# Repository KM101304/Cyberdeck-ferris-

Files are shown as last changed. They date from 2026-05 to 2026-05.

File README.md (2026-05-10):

# Ferris FieldDeck 11

A backpack-portable asymmetrical clamshell cyberdeck built around an 11-inch USB-C tablet and a Ferris Sweep-inspired low-profile split keyboard.

This repo contains a parametric OpenSCAD prototype package intended for real 3D printing and mechanical iteration.

## Locked Design

| Feature | Value |
|---|---:|
| Closed footprint | 282 x 176 mm |
| Lower shell height | 24.8 mm rear structural height |
| Upper lid thickness | 11.2 mm |
| Opening angle target | 122 degrees nominal, 120-125 degree working range |
| Tablet envelope | Samsung Galaxy Tab A9+, 257.1 x 168.7 x 6.9 mm |
| Keyboard | Sweep v2.2 Choc low-profile 34 key |
| Shell material | PETG |
| Structural inserts | M2.5 and M3 brass heat-set inserts |
| Hinge style | Dual compact friction hinges |

## Files

```text
scad/fielddeck.scad          Main parametric source
scad/parts/*.scad            One wrapper per printable part
scripts/export_stls.sh       Batch STL export script
scripts/export_web_models.sh Batch website model export script
exports/stl/                 STL output directory
docs/PRINTING.md             Bambu/PETG print settings
docs/BOM.md                  Hardware, fasteners, and electronics
docs/ASSEMBLY.md             Build sequence and validation checks
docs/AUDIT.md                Engineering audit and remaining prototype checks
docs/PARTS_LOCK.md           Real selected parts and mechanical envelopes
docs/WIRING.md               Keyboard, power, and USB wiring plan
hardware/keyboard/Sweep/     Vendored Sweep v2.2 PCB source and gerbers
hardware/keyboard/fielddeck_sweep_compat/ FieldDeck-specific keyboard PCB placement and wiring files
```

## Printable Parts

| Part | Purpose |
|---|---|
| `lower_left` | Left lower shell with left keyboard tray |
| `lower_right` | Right lower shell with right keyboard tray |
| `lower_center_spine` | Mechanical joiner, hinge spine reinforcement, central seam cover |
| `bottom_cover` | Removable service panel |
| `upper_lid_frame` | Tablet retention frame |
| `upper_lid_back` | Ribbed lid back panel |
| `lower_hinge_block_left/right` | Lower hinge mounts |
| `upper_hinge_block_left/right` | Upper hinge mounts |
| `tablet_bracket` | Hooked sliding tablet retention bracket, print 4 |
| `keyboard_plate_left/right` | Choc switch plates |
| `cable_cover_short/long` | Internal cable channel covers |
| `battery_strap` | Retains internal USB-C PD pack/module |
| `fit_coupon` | Insert, screw, slot, and bracket clearance test |

## Simulated Components

The assembly preview and web viewer include simulated internal components:

- 11-inch tablet massing
- split keyboard PCBs
- Kailh Choc switch bodies
- keycaps
- controller board
- USB-C port boards
- protected battery module
- hinge hardware
- keyboard, battery, and hinge-loop cable runs

The GitHub Pages viewer has an `Internals` mode that makes the shell transparent so those simulated components can be inspected.

## Real Parts Locked

This revision is built around a Samsung Galaxy Tab A9+ Wi-Fi tablet, Sweep v2.2 Choc PCB geometry, and Pro Micro-footprint USB-C RP2040 controllers. See [docs/PARTS_LOCK.md](docs/PARTS_LOCK.md) for selected parts, dimensions, and source links.

## Export STLs

Install OpenSCAD, then run:

```bash
scripts/export_stls.sh
```

The generated files will be placed in:

```text
exports/stl/
```

You can also open any file in `scad/parts/` directly in OpenSCAD and export that individual part.

## Preview The Design

Rendered previews are generated from the same OpenSCAD assembly source as the printable parts.

The GitHub Pages site lives in `docs/` and includes an interactive Three.js STL viewer:

```text
https://km101304.github.io/Cyberdeck-ferris-/
```

```bash
scripts/render_previews.sh
```

Open these files:

| View | File |
|---|---|
| Keyboard/open isometric | [exports/preview/fielddeck_keyboard_iso.png](exports/preview/fielddeck_keyboard_iso.png) |
| Keyboard/top layout | [exports/preview/fielddeck_keyboard_top.png](exports/preview/fielddeck_keyboard_top.png) |
| Display/rear isometric | [exports/preview/fielddeck_open_iso.png](exports/preview/fielddeck_open_iso.png) |
| Display/rear front | [exports/preview/fielddeck_open_front.png](exports/preview/fielddeck_open_front.png) |
| Side profile | [exports/preview/fielddeck_open_side.png](exports/preview/fielddeck_open_side.png) |
| Closed clearance | [exports/preview/fielddeck_closed_iso.png](exports/preview/fielddeck_closed_iso.png) |

## Print First

Before committing to the large shell pieces, print these validation parts:

1. `tablet_bracket`
2. `lower_hinge_block_left`
3. `keyboard_plate_left`
4. `cable_cover_short`
5. `fit_coupon`

Confirm insert fit, hinge hardware spacing, Choc switch fit, and cable clearance.

## Manufacturing Notes

- Use PETG for the main structure.
- Use PETG-CF or nylon for hinge blocks when possible.
- Use 4 wall loops and 25% gyroid infill for shell parts.
- Use 40% infill and 5 wall loops for hinge blocks.
- Add 0.8-1.0 mm TPU, EVA, felt, or Poron pads wherever the tablet contacts printed plastic.
- Tune the tablet bracket slots so the hooks overlap the glass/edge by 2.0-2.5 mm after pads are installed.
- Do not install a raw lithium pack without a protected BMS, fuse, and proper charging board. The intended prototype uses an enclosed slim USB-C PD power bank/module.

## CAD Iteration

The OpenSCAD package is the printable mechanical baseline. For Fusion 360 refinement:

1. Export the part STLs from OpenSCAD.
2. Import into Fusion as reference meshes.
3. Rebuild critical surfaces parametrically if you need production-level CAD.
4. Preserve the dimensions and interface locations from `scad/fielddeck.scad`.

## Current Status

The repo now contains both the parametric OpenSCAD source and generated STL files in `exports/stl/`. The STL export was verified with OpenSCAD CGAL rendering; every exported part reported as a valid simple 3D object. See [docs/AUDIT.md](docs/AUDIT.md) for the latest engineering audit.

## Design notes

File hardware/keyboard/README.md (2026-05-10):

# Keyboard PCB Package

This project uses the open-source Sweep v2.2 low-profile Choc PCB as the production keyboard PCB.

The upstream hardware source is vendored here:

```text
hardware/keyboard/Sweep/
```

Key files:

```text
hardware/keyboard/Sweep/Sweep v2.2/sweepv2.kicad_pcb
hardware/keyboard/Sweep/Sweep v2.2/sweepv2_plate.kicad_pcb
hardware/keyboard/Sweep/Sweep v2.2/sweepv2.2_gerber.zip
```

The Gerber ZIP is ready to upload to a PCB manufacturer. The cyberdeck shell uses its own recessed trays and mounting bosses, so the original Sweep case/plate geometry should be treated as a PCB reference rather than the final enclosure.

FieldDeck-specific wiring, placement, and mechanical integration files are in:

```text
hardware/keyboard/fielddeck_sweep_compat/
```

Use Pro Micro-footprint USB-C RP2040 controllers for the FieldDeck build. The earlier XIAO controller concept is no longer recommended because it is a poor fit for the direct-pin Sweep v2.2 architecture.

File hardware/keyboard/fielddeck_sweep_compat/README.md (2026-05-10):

# FieldDeck Sweep-Compatible Keyboard PCB Package

This folder defines the cyberdeck-specific keyboard integration.

Decision: use the open-source Sweep v2.2 Choc PCB geometry as the manufacturable base, because it is generic, easy to find online, already proven by the keyboard community, and already vendored in this repo with a Gerber ZIP.

The FieldDeck-specific changes are enclosure and wiring decisions:

- Pro Micro-footprint USB-C RP2040 controllers instead of XIAO controllers.
- Internal keyed JST-SH split interconnect instead of exposed TRRS.
- Recessed tray and printed switch plate matched to the cyberdeck shell.
- Lowered keyboard mounting plane for clamshell closure clearance.

## Fab-Ready PCB Source

Use the upstream Sweep v2.2 Gerber ZIP:

```text
../Sweep/Sweep v2.2/sweepv2.2_gerber.zip
```

The archive contains a JLCPCB-ready package named `sweepv2.1_216.92x86.863892mm_for_JLCPCB/`.

## FieldDeck Design Files

| File | Purpose |
|---|---|
| `switch_coordinates.csv` | Switch center coordinates used by the CAD and PCB spec |
| `direct_pin_netlist.csv` | One-GPIO-per-key wiring map for each half |
| `interconnect_pinout.csv` | Internal keyed split interconnect pinout |
| `pcb_mechanical_spec.md` | Mechanical envelope, mounting holes, and clearance rules |
| `fielddeck_keyboard_layout.svg` | Human-readable board/layout drawing |

## Controller

Use SparkFun Pro Micro RP2040 or another Pro Micro-footprint USB-C RP2040 controller with equivalent pin availability. SparkFun lists the board as USB-C, Pro Micro footprint, and `1.3 in x 0.7 in`, which is inside the CAD controller envelope.

## Why Not XIAO

The Seeed XIAO RP2040 is attractive and small, but this design uses a direct-pin Sweep-style circuit. Each 17-key half needs 17 switch GPIO plus split communication and reset/programming support. XIAO pushes that into an avoidable I/O compromise. Pro Micro RP2040 keeps the board generic and sourceable.

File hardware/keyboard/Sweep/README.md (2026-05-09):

# Sweep
<!--
           ___                        ___
      ___ |   | ___ ___      ___ ___ |   | ___
 ___ |   |`___`|   |   |    |   |   |`___`|   | ___
|   |`___`|   |`___`___`    `___`___`|   |`___`|   |
`___`|   |`___`|   |   |    |   |   |`___`|   |`___`
|   |`___`|   |`___`___`    `___`___`|   |`___`|   |
`___`|   |`___`|   |   |    |   |   |`___`|   |`___`
|   |`___`     `___`___`    `___`___`     `___`|   |
`___`           ___ ___      ___ ___           `___`
               |   |   |    |   |   |
               `___`___`    `___`___`
-->
>  sweep-hero  
> <sub>Bluetooth Sweep 2 + MBK Legend Keycaps</sub>

<span>
  <a href="https://discord.gg/czXcTXbsgU">
    
  </a>
  
  
  
</span>

## What is sweep?

Sweep is a version of the more fabulous [Ferris](https://github.com/pierrechevalier83/ferris) by [Pierre Chevalier](https://github.com/pierrechevalier83/) that uses a daughter board like a promicro, elite-c, bit-c, nice!nano etc. instead of using onboard components.

## What are the different types?

⭐ Sweep 2 - Recommended Choc v1 board with all the features.  
⭕ Sweep Half Swept - Same as Sweep 2, but with a reversible pro-micro footprint.  
⭕ Sweep Bling MX - An MX only Sweep that features Kailh's hotswap sockets and a stacked case.  
⭕ Sweep Bling LP - A Choc v1 only Sweep that features Kailh's hotswap sockets.  
⭕ Sweep High - Same as the Sweep 2, but trades choc spacing for compatibility with more switches and keycaps.  
⭕ Sweep High M - A soldered MX only Sweep, with a reversible PCB design.  
⭕ Sweep Mini - The only version that supports Choc minis.  

| Device | On/Off Switch<sup>[1]</sup> | Reversible PCB<sup>[2]</sup> | Choc V1 | Choc V2 | Choc Mini | MX & Alps | Choc Spacing<sup>[3]</sup> | Tenting<sup>[4]</sup> | Hot Swap |
| :--- | :---: | :---: | :---: | :---: | :---: | :---: | :---: | :---: | :---: |
| Sweep2.x | ✔ | | ✔ | | | | ✔ | ✔ | Mill-Max (optional) |
| Sweep Bling LP | ✔ | | ✔ | | | | ✔ | ✔ | Kailh (required) |
| Sweep Bling MX | ✔ | ✔ | | | | ⚠<br/><sup>[5]</sup> | | ✔ | Kailh (required) |
| Sweep High | ✔ | | ✔ | ✔ | | ✔ | | ✔ |
| Sweep High M | ✔ | ✔ | | | | MX | | ✔ | |
| Sweep Half Swept  | ✔ | ✔ | ✔ | | | | ✔ | ✔ | Mill-Max (optional) |
| Sweep Mini | | ✔ | | | ✔ | | ✔ | |

> Note: All versions support bluetooth with Nice!Nano

*<sup>[1]</sup> An on/off switch is recommended for bluetooth builds.*  
*<sup>[2]</sup> With a reversible PCB it's easier to make mistakes during assembly, but it allows you to purchase less boards.*  
*<sup>[3]</sup> Choc spaced boards have the switches in a tighter grid. This provides a better final look but is only compatible with some choc keycaps. (e.g. MBK)*  
*<sup>[4]</sup> Supports splitkb's [tenting puck.](https://splitkb.com/products/tenting-puck?_pos=1&_psq=tenting%20&_ss=e&_v=1.0)*  
*<sup>[5]</sup> MX + kailh hotswap ONLY. Alps are NOT supported.*  

## Components list

To build and use a Sweep you will need:

* 1x PCB Kit
* 2x promicro compatible boards or 2 nice!nanos.
* 34 switches of a compatible type (refer to the compatibility table)
* 34 keycaps
* 2x reset switches (optional; [B3U-1000P(M)](https://github.com/davidphilipbarr/Sweep/issues/20))
* Some little rubber feet/bumpers
* 2x power switches (optional if supported; MSK 12C02)
* 1x TRRS (not TRS!) cable (wired build only)
* 2x TRRS Jack [PJ-320A] (wired build only)
* 1 USB Cable (depends on your micro-controller choice)

## How do I make this thing?

<a href="https://www.youtube.com/watch?v=fBPu7AyDtkM" target="_blank">
  
</a>

## Firmware

The firmware can be found [with the Ferris  firmware as part of QMK](https://github.com/qmk/qmk_firmware/tree/master/keyboards/ferris/sweep).

Firmware for zmk and bluemicro_ble is called ["Cradio"](https://zmk.dev/docs/hardware/).

## Who made this?

* [Pierre Chevalier](https://github.com/pierrechevalier83)
* [David Barr](https://github.com/davidphilipbarr)
* [Ibnu Daru Aji](https://github.com/ibnuda/)
* [Duccio](https://github.com/duckyb)

## Featured Forks ✨

* [Sweep Gateron](https://github.com/drewlwhitney/Sweep-Gateron) by drewlwhitney: *A Sweep High modded with Gateron-LP KS-33 support.*

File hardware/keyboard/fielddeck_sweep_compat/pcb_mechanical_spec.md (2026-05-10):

# FieldDeck Sweep-Compatible PCB Mechanical Spec

## Board Envelope

| Item | Value |
|---|---:|
| Per-half PCB target envelope | 108 x 86 x 1.6 mm |
| Printed tray pocket | 116 x 90 mm |
| Printed switch plate | 112 x 88 x 1.6 mm |
| Controller keepout | 34 x 18.5 x 5.0 mm |
| Mounting screws | M2.5, 4 per half |
| Mounting hole centers | +/-46 x +/-32 mm from each half local origin |

## Vertical Stack

| Stack Item | CAD Z |
|---|---:|
| Lower shell top rear datum | 24.8 mm |
| Keyboard PCB underside | 12.0 mm |
| Keyboard plate underside | 17.0 mm |
| Nominal keycap top | 22.6 mm |
| Closed lid clearance target | 2.0 mm minimum |

The keyboard stack now clears the lower shell rear datum by about `2.2 mm` before soft pads, print tolerance, and lid inner relief are considered.

## Layout

The layout is a Sweep/Ferris-style 17-key half:

- 5 columns x 3 rows
- 2 thumb keys
- 18 mm column pitch
- 17 mm row pitch
- 11 degree half splay in the enclosure

## Fabrication Notes

Use 1.6 mm FR-4, 1 oz copper, ENIG or HASL finish. Order the first boards from the vendored Sweep v2.2 Gerbers before commissioning a cosmetic custom PCB spin.

If a custom FieldDeck PCB spin is made later, preserve:

- Switch centers from `switch_coordinates.csv`
- Mount hole centers from this file
- Per-half envelope under `108 x 86 mm`
- Controller connector toward the rear/service side
- No components taller than the controller USB-C shell inside the keyboard tray

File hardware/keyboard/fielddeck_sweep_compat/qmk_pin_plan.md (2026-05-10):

# QMK Pin Plan

This is the firmware-facing pin plan for the FieldDeck Sweep-compatible keyboard.

Use an existing Sweep/Ferris QMK keyboard as the firmware base, then convert the controller target to the selected Pro Micro RP2040 board.

## Direct Pins

The FieldDeck plan keeps the Sweep-style direct-pin circuit: each switch closes one controller GPIO to ground. There are no row/column diodes in this baseline.

```c
// Logical order per half, matching switch_coordinates.csv.
// Replace these labels with the exact QMK pin names for the chosen Pro Micro RP2040 board.
#define DIRECT_PINS { \
  { D2, D3, D4, D5, D6 }, \
  { D7, D8, D9, D10, D14 }, \
  { D15, D16, D18, D19, D20 }, \
  { NO_PIN, NO_PIN, NO_PIN, D21, D22 } \
}
```

## Split Transport

```c
#define SOFT_SERIAL_PIN D1
#define SPLIT_USB_DETECT
#define MASTER_LEFT
```

## Notes

- Confirm pin names against the exact controller package before flashing.
- If using a SparkFun Pro Micro RP2040, use the QMK RP2040 Pro Micro conversion target or equivalent board definition.
- The right half receives power and serial over the internal JST-SH-4 cable.
- Keep reset accessible through the bottom service cover during firmware bring-up.

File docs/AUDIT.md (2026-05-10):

# Ferris FieldDeck 11 Design Audit

## Summary

The current prototype is suitable for first-round printed fit testing after one functional correction: the keyboard stack has been lowered so the keycap tops no longer sit above the lower shell rear datum. The remaining risk is concentrated around final purchased hinge screw pattern, physical USB-C cable bend behavior, and exact controller pin mapping during firmware bring-up.

## Functional Audit

| System | Result | Evidence | Required Action |
|---|---|---|---|
| Hinge open angle | Pass for CAD prototype | Lid is modeled around the hinge axis at 122 degrees with printed hard stops at the rear spine. | Match final metal hinge leaf screw pattern before final hinge-block print. |
| Hinge closure | Conditional pass | Added `closed_preview` so the closed envelope can be inspected. Hinge barrels are coaxial in CAD and relief diameter is `hinge_barrel_d + 0.8 mm`. | Print one hinge block pair and hand-cycle with the purchased hinges before printing full shells. |
| Keyboard closed clearance | Fixed | Previous keycap top was about `27.2 mm`, above the `24.8 mm` lower shell height. CAD now sets `keyboard_mount_z = 13.8 mm` and nominal keycap top to `22.6 mm`. | Verify real PCB, socket, switch, and keycap stack is not taller than the CAD stack. |
| Keyboard PCB fit | Pass with selected PCB class | Per-half CAD PCB envelope is now `108 x 86 mm`, tray pocket is `116 x 90 mm`, and plate is `112 x 88 mm`. | Use Sweep v2.2-compatible Choc PCBs or preserve these envelopes in a custom spin. |
| Keyboard electronics | Pass after controller change | XIAO RP2040 was rejected. Pro Micro-footprint USB-C RP2040 controllers match the existing Sweep v2.2 architecture and provide enough GPIO for direct-pin halves. | Use `hardware/keyboard/fielddeck_sweep_compat/` wiring files. |
| Tablet retention | Pass for prototype | Hooked sliding brackets have 14 x 3.2 mm adjustment slots, pad relief, and 2.0-2.5 mm overlap target. | Install 0.8-1.0 mm soft pads and verify no hard plastic contacts glass. |
| Battery/serviceability | Pass for first prototype | Battery bay, rails, strap, bottom access holes, and rear I/O boards are modeled. | Use only a protected USB-C PD module fitting the bay. |

## Fixes Applied

| Area | Audit Finding | Design Response |
|---|---|---|
| Keyboard mounting | Original bosses were too low relative to the recessed tray stack-up. | Bosses now extend to the plate screw plane. |
| Serviceability | The bottom cover needed clear bottom-side screw access. | Bottom access holes were added for cover and battery strap screws. |
| Power module | Battery volume needed visible retention geometry. | Added cradle rails and strap bosses for a slim protected USB-C PD module. |
| Hinge behavior | The hinge area needed explicit over-travel control. | Added printed hinge stop blocks at the rear spine. |
| Cable routing | Cable intent needed to be visible and testable. | Added simulated keyboard interconnect, battery-to-port, and hinge service-loop cable runs. |
| Electronics massing | Internal parts were not represented in the assembly. | Added simulated controller, port boards, keyboard PCBs, Choc switches, tablet, keycaps, and hinge hardware. |
| Website preview | Single STL was hard to inspect. | Split web models into shell, tablet, keycaps, and components with an Internals viewing mode. |
| Tablet fit | Generic 11-inch tablet left too much bezel/dead space. | Locked Samsung Galaxy Tab A9+ and reduced shell to 282 x 176 mm with 11.2 mm lid thickness. |
| Ports | Rear I/O was only conceptual. | Added USB-C keyboard/service, USB-A accessory/service, USB-C PD input, and power switch cutouts. |
| PCB readiness | Keyboard PCB was only simulated. | Vendored upstream Sweep v2.2 KiCad files and Gerber ZIP under `hardware/keyboard/Sweep`. |
| Slimming pass | The first real-parts shell still carried extra dead space in height, hinge spacing, service cover, and bracket layout. | Reduced footprint to 282 x 176 mm, lower shell to 24.8 mm, lid to 11.2 mm, battery bay to 108 x 52 x 13 mm, and moved the keyboard trays forward 2 mm. |
| Hinge realism | Generic hinge blocks did not prove barrel clearance or leaf seating. | Added 8 mm-class hinge barrel reliefs, shallow metal-leaf pockets, M3 screw holes, coaxial visual barrels, and compact hard stops at the rear spine. |
| Tablet retention | The prior clips were simple blocks and did not positively capture the tablet. | Replaced them with hooked sliding brackets with 14 x 3.2 mm adjustment slots, 2.0-2.5 mm edge overlap target, and soft-pad relief. |
| Keyboard closure | The lowered shell made the prior keycap stack too tall. | Lowered the keyboard mounting plane, deepened the tray relief, and added a closed-preview export. |
| Keyboard PCB | XIAO controller choice did not match the direct-pin Sweep v2.2 board. | Switched to Pro Micro-footprint USB-C RP2040 controllers and added FieldDeck-specific PCB/wiring files. |

## Remaining Prototype Checks

1. Confirm the exact USB-C port location on the physical Galaxy Tab A9+ before final cable-channel tuning.
2. Match hinge screw pattern to the purchased friction hinge before printing final hinge blocks; the model assumes an 8.2 mm barrel and 30 mm barrel length.
3. Print `fit_coupon.stl` before shell parts and tune heat-set insert hole diameters if needed.
4. Verify hooked tablet brackets clamp with pad compression but do not press hard plastic directly into the glass or aluminum body.
5. Verify keycap-to-lid closed clearance with real switches, caps, PCB, plate, and gasket stack; target keycap top is `22.6 mm` from lower shell datum.
6. Verify the USB-C service loop does not pinch through ten slow open-close cycles.
7. Confirm Pro Micro RP2040 pin names in firmware before ordering a custom FieldDeck PCB spin.
8. Confirm the protected power module can be removed through the bottom service path.

## Current Recommendation

Proceed with a mechanical fit prototype using PETG for the shell and PETG-CF or nylon for the hinge blocks. Order or build the keyboard from the vendored Sweep v2.2 Gerbers first; commission a cosmetic custom PCB only after the printed tray and closed-clearance checks pass. Do not install raw lithium cells in this revision; use an enclosed protected USB-C PD power module.

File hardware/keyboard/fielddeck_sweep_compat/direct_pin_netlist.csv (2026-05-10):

half | key | controller_signal | net | other_switch_pin
left | L01 | D2 | L_SW01 | GND
left | L02 | D3 | L_SW02 | GND
left | L03 | D4 | L_SW03 | GND
left | L04 | D5 | L_SW04 | GND
left | L05 | D6 | L_SW05 | GND
left | L06 | D7 | L_SW06 | GND
left | L07 | D8 | L_SW07 | GND
left | L08 | D9 | L_SW08 | GND
left | L09 | D10 | L_SW09 | GND
left | L10 | D14 | L_SW10 | GND
left | L11 | D15 | L_SW11 | GND
left | L12 | D16 | L_SW12 | GND
left | L13 | D18 | L_SW13 | GND
left | L14 | D19 | L_SW14 | GND
left | L15 | D20 | L_SW15 | GND
left | L16 | D21 | L_SW16 | GND
left | L17 | D22 | L_SW17 | GND
right | R01 | D2 | R_SW01 | GND
right | R02 | D3 | R_SW02 | GND
right | R03 | D4 | R_SW03 | GND
right | R04 | D5 | R_SW04 | GND
right | R05 | D6 | R_SW05 | GND
right | R06 | D7 | R_SW06 | GND
right | R07 | D8 | R_SW07 | GND
right | R08 | D9 | R_SW08 | GND
right | R09 | D10 | R_SW09 | GND
right | R10 | D14 | R_SW10 | GND
right | R11 | D15 | R_SW11 | GND
right | R12 | D16 | R_SW12 | GND
right | R13 | D18 | R_SW13 | GND
right | R14 | D19 | R_SW14 | GND
right | R15 | D20 | R_SW15 | GND
right | R16 | D21 | R_SW16 | GND
right | R17 | D22 | R_SW17 | GND

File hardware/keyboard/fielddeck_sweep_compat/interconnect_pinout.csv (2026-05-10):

connector | pin | signal | wire_color | recommended_use
JST-SH-4 | 1 | GND | black | common ground
JST-SH-4 | 2 | 3V3 | red | right half power
JST-SH-4 | 3 | SERIAL | yellow | QMK split serial data
JST-SH-4 | 4 | RESET | white | optional remote reset or no-connect

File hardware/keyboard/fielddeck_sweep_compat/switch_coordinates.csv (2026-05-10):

half | key | x_mm | y_mm | row | column | role
left | L01 | -36 | 20 | 0 | 0 | key
left | L02 | -18 | 15 | 0 | 1 | key
left | L03 | 0 | 11 | 0 | 2 | key
left | L04 | 18 | 15 | 0 | 3 | key
left | L05 | 36 | 20 | 0 | 4 | key
left | L06 | -36 | 3 | 1 | 0 | key
left | L07 | -18 | -2 | 1 | 1 | key
left | L08 | 0 | -6 | 1 | 2 | key
left | L09 | 18 | -2 | 1 | 3 | key
left | L10 | 36 | 3 | 1 | 4 | key
left | L11 | -36 | -14 | 2 | 0 | key
left | L12 | -18 | -19 | 2 | 1 | key
left | L13 | 0 | -23 | 2 | 2 | key
left | L14 | 18 | -19 | 2 | 3 | key
left | L15 | 36 | -14 | 2 | 4 | key
left | L16 | 18 | -42 | 3 | 3 | thumb
left | L17 | 39 | -36 | 3 | 4 | thumb
right | R01 | 36 | 20 | 0 | 0 | key
right | R02 | 18 | 15 | 0 | 1 | key
right | R03 | 0 | 11 | 0 | 2 | key
right | R04 | -18 | 15 | 0 | 3 | key
right | R05 | -36 | 20 | 0 | 4 | key
right | R06 | 36 | 3 | 1 | 0 | key
right | R07 | 18 | -2 | 1 | 1 | key
right | R08 | 0 | -6 | 1 | 2 | key
right | R09 | -18 | -2 | 1 | 3 | key
right | R10 | -36 | 3 | 1 | 4 | key
right | R11 | 36 | -14 | 2 | 0 | key
right | R12 | 18 | -19 | 2 | 1 | key
right | R13 | 0 | -23 | 2 | 2 | key
right | R14 | -18 | -19 | 2 | 3 | key
right | R15 | -36 | -14 | 2 | 4 | key
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

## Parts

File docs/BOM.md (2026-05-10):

# Ferris FieldDeck 11 Bill Of Materials

## Printed Parts

| File | Qty |
|---|---:|
| lower_left.stl | 1 |
| lower_right.stl | 1 |
| lower_center_spine.stl | 1 |
| bottom_cover.stl | 1 |
| upper_lid_frame.stl | 1 |
| upper_lid_back.stl | 1 |
| lower_hinge_block_left.stl | 1 |
| lower_hinge_block_right.stl | 1 |
| upper_hinge_block_left.stl | 1 |
| upper_hinge_block_right.stl | 1 |
| tablet_bracket.stl | 4 |
| keyboard_plate_left.stl | 1 |
| keyboard_plate_right.stl | 1 |
| cable_cover_short.stl | 2 |
| cable_cover_long.stl | 1 |
| battery_strap.stl | 1 |
| fit_coupon.stl | 1 optional |

## Hardware

| Item | Qty |
|---|---:|
| M2.5 x 6 button head screws | 40 |
| M2.5 x 8 button head screws | 12 |
| M3 x 6 button head screws | 24 |
| M3 x 8 button head screws | 24 |
| M3 x 10 button head screws | 8 |
| M2.5 heat-set inserts, Voron style | 50 |
| M3 heat-set inserts, Voron style | 40 |
| 3 mm alignment pins | 6 |
| Rubber feet, 8-10 mm | 6 |
| Compact friction hinges, 0.25-0.45 N-m, 8-10 mm barrel, 28-35 mm barrel length | 2 |
| 0.8-1.0 mm EVA/Poron/TPU pad strips for tablet bracket hooks | 4 |

## Electronics

| Item | Qty |
|---|---:|
| Samsung Galaxy Tab A9+ Wi-Fi 64 GB SM-X210 | 1 |
| Kailh Choc v1 switches | 34 |
| Choc keycaps | 34 |
| Sweep v2.2 low-profile PCB pair | 1 |
| SparkFun Pro Micro RP2040 or pin-compatible USB-C Pro Micro RP2040 controller | 2 |
| JST-SH 4-pin cable, 150-180 mm | 1 |
| Short right-angle USB-C cable | 1 |
| Slim protected USB-C PD power bank/module, max 108 x 52 x 10.5 mm preferred | 1 |
| Adafruit USB Type-C Breakout 4090 | 1 |
| Adafruit HUSB238 USB-C PD Switchable Breakout 5991 | 1 |
| USB-A panel/breakout board, max 24 x 18 x 6 mm | 1 |
| 26-28 AWG silicone wire | as needed |
| Low-profile machine-pin sockets for Pro Micro controllers | 2 sets |
| 1 mm EVA/Poron/TPU pad sheet | 1 |

## Simulated In CAD

The preview assembly includes non-print reference geometry for the battery module, controller, port boards, cables, switch bodies, keycaps, tablet, and hinge barrels. These are for clearance and rendering context, not final electronics fabrication.

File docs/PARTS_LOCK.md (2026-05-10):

# Ferris FieldDeck 11 Parts Lock

This revision locks the mechanical design around real, inexpensive, orderable parts rather than generic placeholders.

## Tablet

**Chosen part:** Samsung Galaxy Tab A9+ Wi-Fi, 64 GB, Graphite, model family SM-X210.

Source: Samsung product/spec pages list the Tab A9+ at 168.7 x 257.1 x 6.9 mm with an 11.0 inch display.

| Parameter | Value |
|---|---:|
| Body | 257.1 x 168.7 x 6.9 mm |
| Display | 11.0 in, 1920 x 1200 |
| USB | USB-C, USB 2.0 |
| Reason | Cheap, common in the US, thin, relatively small bezels for a budget tablet, and stable Samsung supply chain. |

Design clearance in CAD:

| Interface | Value |
|---|---:|
| Tablet recess clearance | +0.7 mm total |
| Soft pad thickness | 0.8-1.0 mm TPU/EVA/felt |
| Bracket overlap | 2.0-2.5 mm nominal |
| Bracket adjustment slot | 14 x 3.2 mm |

## Keyboard PCB

**Chosen board:** Sweep v2.2 low-profile Choc PCB by David Philip Barr, inspired by Ferris.

Source: https://github.com/davidphilipbarr/Sweep

The repo now vendors the upstream hardware source and gerbers:

```text
hardware/keyboard/Sweep/Sweep v2.2/sweepv2.kicad_pcb
hardware/keyboard/Sweep/Sweep v2.2/sweepv2_plate.kicad_pcb
hardware/keyboard/Sweep/Sweep v2.2/sweepv2.2_gerber.zip
```

Use `sweepv2.2_gerber.zip` for PCB ordering. Use the printed shell trays as the mechanical carrier, not the original open keyboard case.

FieldDeck-specific keyboard files:

```text
hardware/keyboard/fielddeck_sweep_compat/
```

This folder defines switch coordinates, direct-pin netlist, internal JST interconnect pinout, and the mechanical PCB envelope used by the shell.

## Controller

**Chosen part:** SparkFun Pro Micro RP2040 or pin-compatible USB-C Pro Micro RP2040 controller.

Source: SparkFun lists the Pro Micro RP2040 with USB-C, Pro Micro footprint, 20 multifunction GPIO pins, and 1.3 x 0.7 in dimensions.

| Parameter | Value |
|---|---:|
| Board envelope used in CAD | 34 x 18.5 x 5.0 mm |
| USB | USB-C |
| Role | Split keyboard controller |

Reason: Pro Micro-footprint controllers match the existing Sweep v2.2 PCB and have enough GPIO for a direct-pin 17-key half. XIAO RP2040 is rejected for this revision because it would require an I/O expander or a matrix redesign.

## USB / Power Boards

| Function | Part | CAD Envelope |
|---|---|---:|
| Keyboard USB-C service | Adafruit USB Type-C Breakout 4090 | 20.4 x 14.2 x 5.0 mm |
| PD input selector | Adafruit HUSB238 USB-C PD Switchable Breakout 5991 | 29.1 x 20.3 x 10.1 mm |
| USB-A accessory/service | Generic USB-A panel/breakout board | 24 x 18 x 6 mm |

Sources:

- Adafruit 4090: https://www.adafruit.com/product/4090
- Adafruit 5991: https://www.adafruit.com/product/5991

## Exterior Ports

Rear edge, left-to-right:

1. USB-C keyboard/service
2. USB-A accessory/service
3. USB-C PD input/charge
4. small power switch

## Hinge

**Chosen class:** two compact laptop-style friction hinges.

Minimum spec:

| Parameter | Value |
|---|---:|
| Torque | 0.25-0.45 N-m each |
| Barrel diameter | 9-10 mm |
| Barrel length | 28-35 mm |
| Screws | M3 |

CAD baseline:

| Interface | Value |
|---|---:|
| Hinge X centers | +/-88 mm |
| Modeled barrel | 8.2 mm diameter x 30 mm long |
| Barrel relief | +0.8 mm clearance |
| Lower block | 34 x 20 x 14 mm |
| Upper block | 32 x 17 x 9 mm |
| Opening hard stop | 122 degrees nominal |

The printed hinge blocks are intentionally still parametric because cheap replacement laptop hinges vary. Match the final screw pattern to the hinge you buy before printing the final lid and hinge blocks.

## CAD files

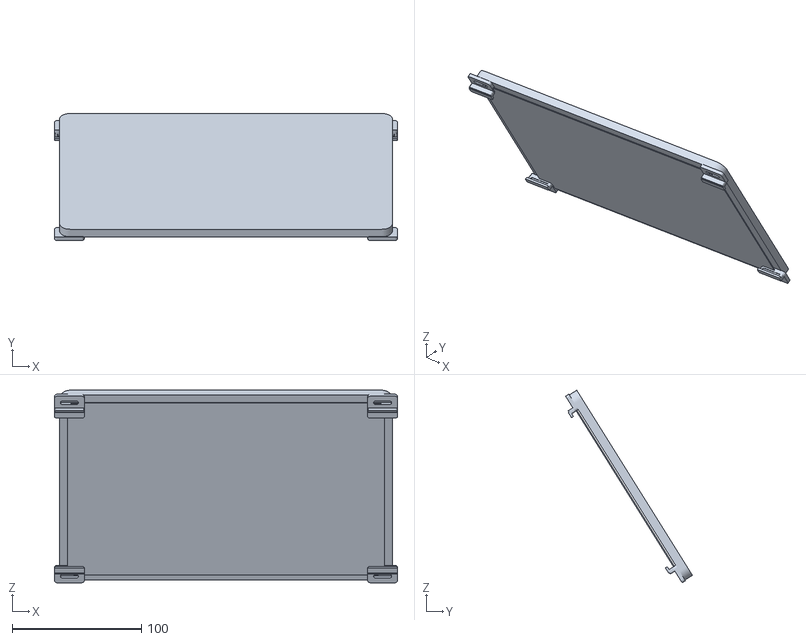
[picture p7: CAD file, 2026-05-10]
docs/assets/models/fielddeck_tablet.stl
265.0 x 98.1 x 148.8

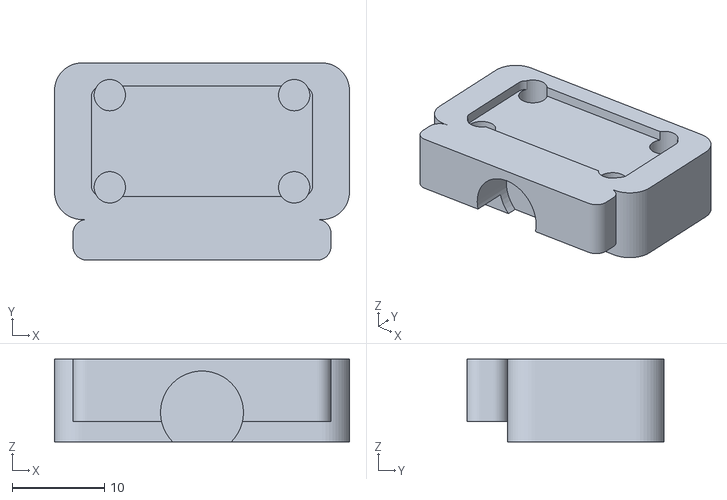
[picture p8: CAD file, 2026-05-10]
exports/stl/upper_hinge_block_left.stl
32.0 x 21.4 x 9.00

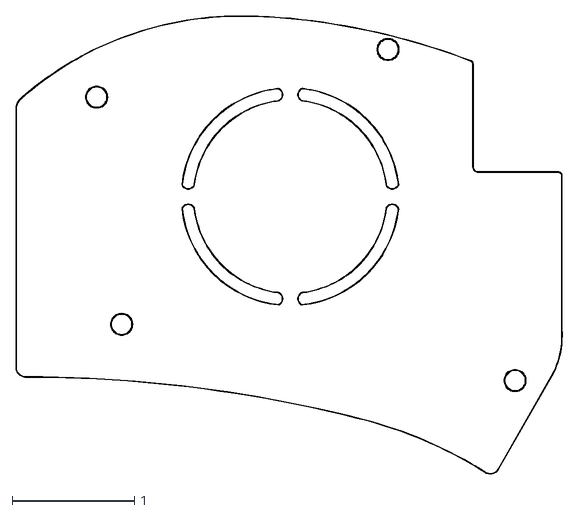
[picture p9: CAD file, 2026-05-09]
hardware/keyboard/Sweep/Sweep Bling MX/bottom-plate/sweep-bling-mx__bottom.dxf
4.47 x 3.75

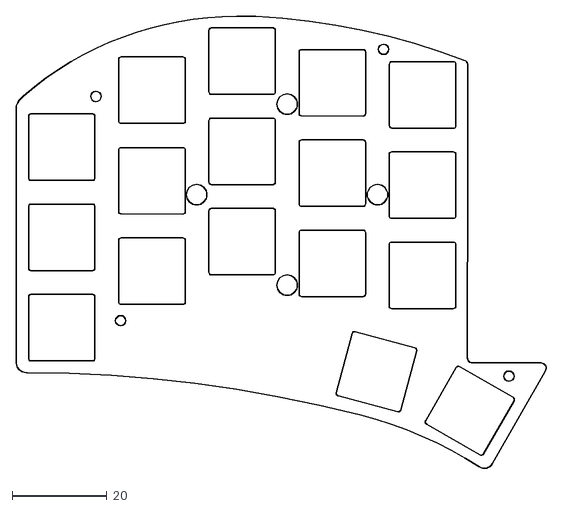
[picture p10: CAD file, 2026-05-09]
hardware/keyboard/Sweep/Sweep Bling MX/gerbers/sweep-bling-mx__plate-lasercut.dxf
111.6 x 95.2

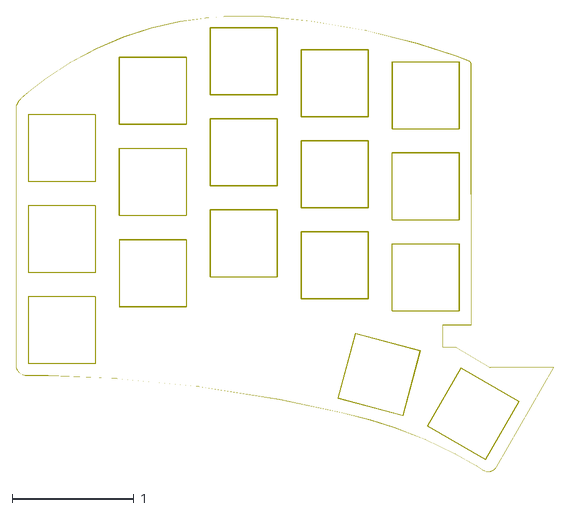
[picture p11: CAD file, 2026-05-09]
hardware/keyboard/Sweep/Sweep High/sweep-high-top-plate.dxf
4.42 x 3.75

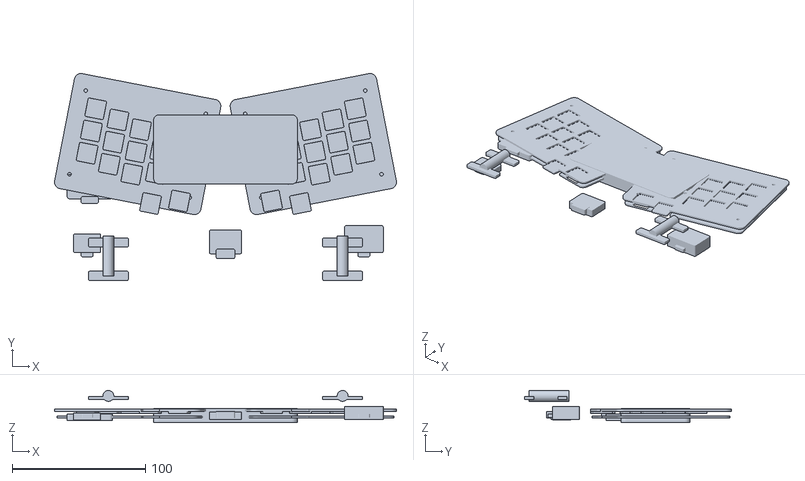
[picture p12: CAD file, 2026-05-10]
docs/assets/models/fielddeck_components.stl
257.0 x 155.5 x 24.1

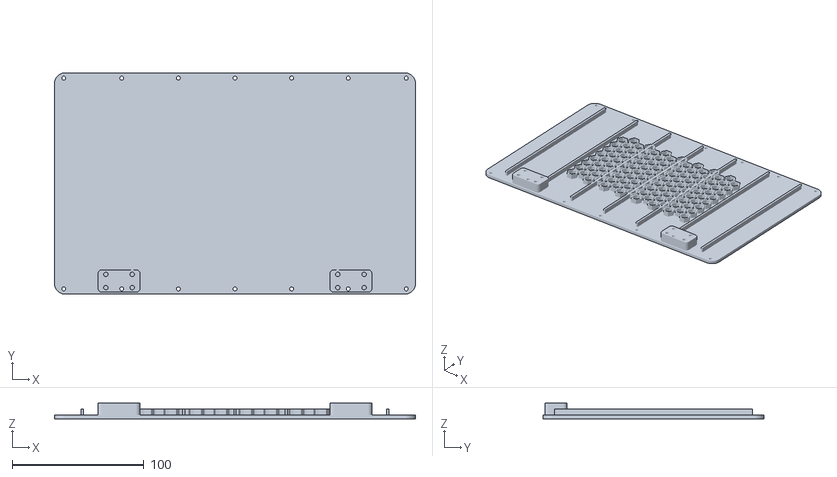
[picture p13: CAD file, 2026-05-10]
exports/stl/upper_lid_back.stl
274.0 x 168.0 x 11.8

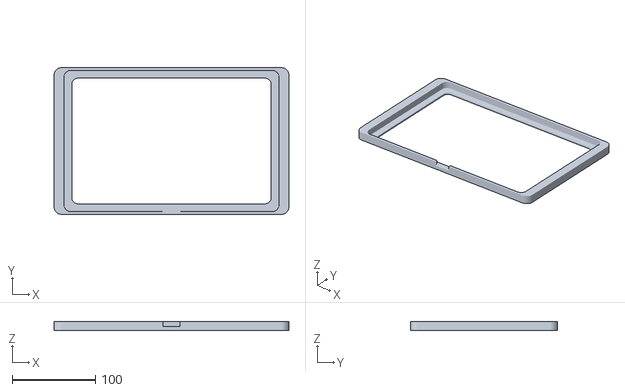
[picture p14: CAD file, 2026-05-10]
exports/stl/upper_lid_frame.stl
282.0 x 176.0 x 11.2

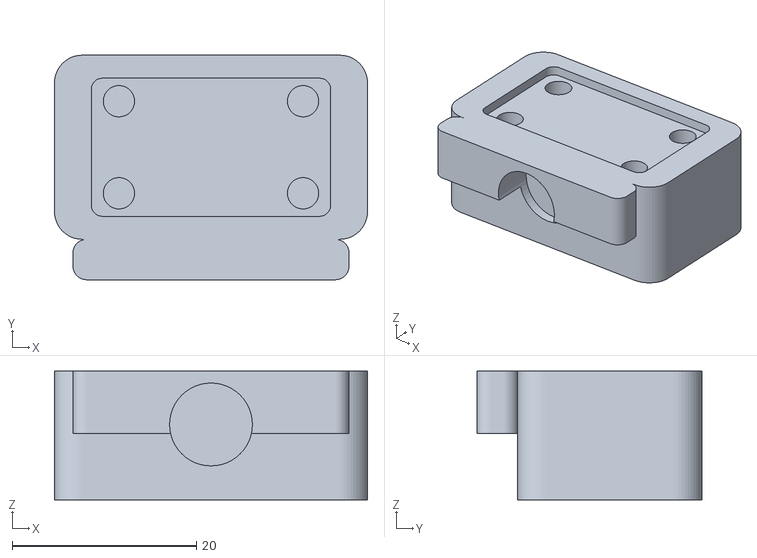
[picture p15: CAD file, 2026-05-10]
exports/stl/lower_hinge_block_right.stl
34.0 x 24.4 x 14.0

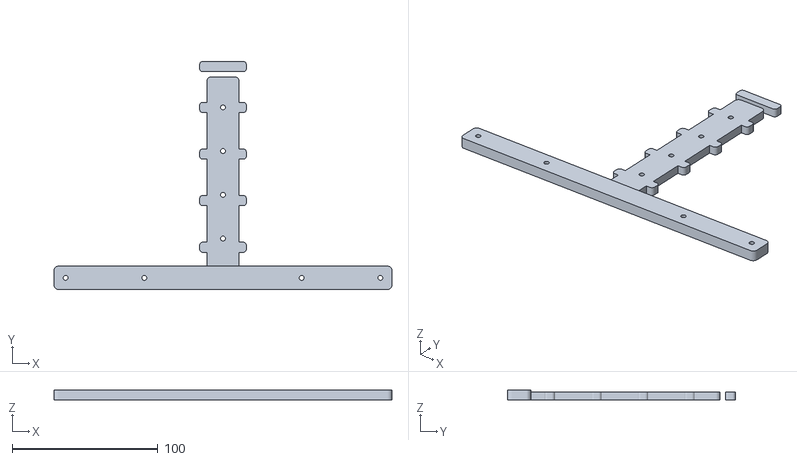
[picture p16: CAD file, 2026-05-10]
exports/stl/lower_center_spine.stl
232.0 x 156.5 x 7.00

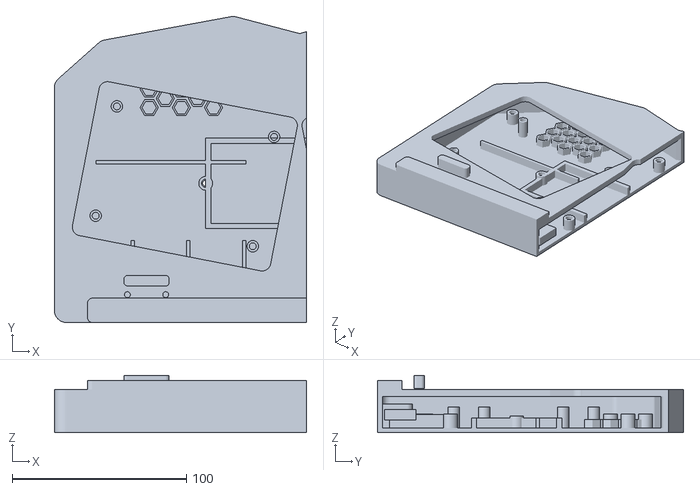
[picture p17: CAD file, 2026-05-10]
exports/stl/lower_left.stl
145.0 x 175.8 x 32.8

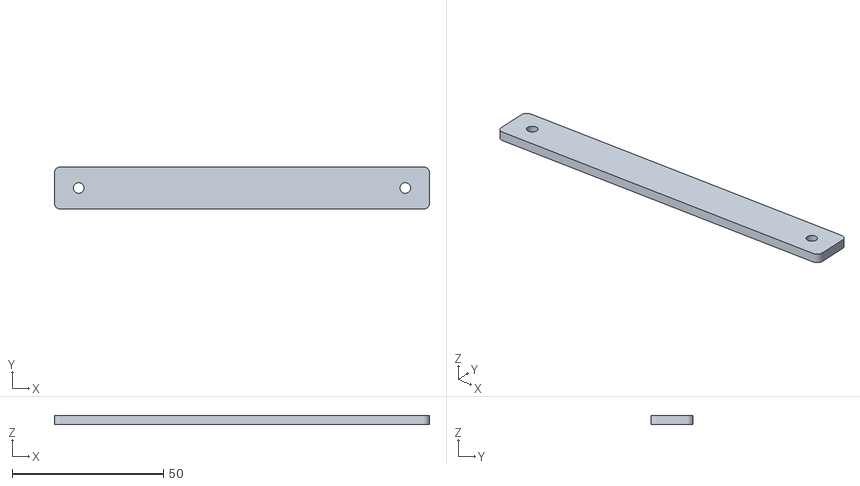
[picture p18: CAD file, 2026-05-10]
exports/stl/battery_strap.stl
124.0 x 14.0 x 3.00

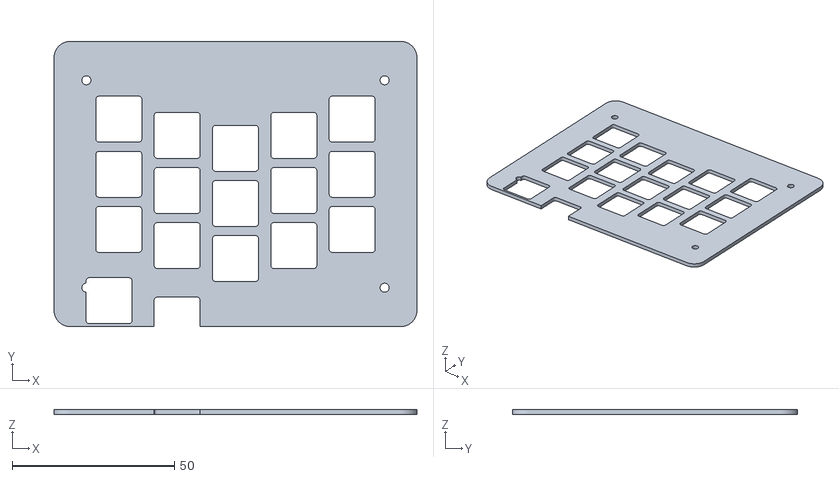
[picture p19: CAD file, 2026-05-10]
exports/stl/keyboard_plate_right.stl
112.0 x 88.0 x 1.60

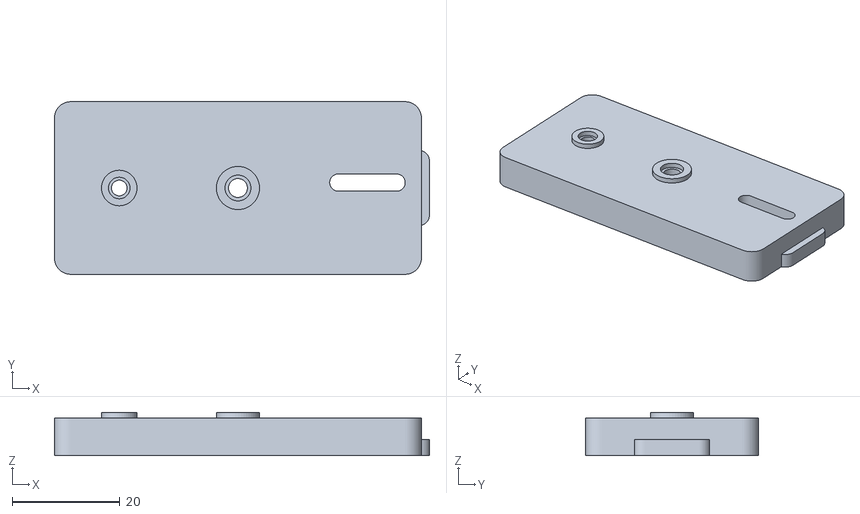
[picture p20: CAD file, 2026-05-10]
exports/stl/fit_coupon.stl
69.5 x 32.0 x 8.00

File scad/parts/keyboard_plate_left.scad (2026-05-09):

PART = "keyboard_plate_left";
include <../fielddeck.scad>;

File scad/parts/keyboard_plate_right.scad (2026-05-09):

PART = "keyboard_plate_right";
include <../fielddeck.scad>;

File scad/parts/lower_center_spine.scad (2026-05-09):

PART = "lower_center_spine";
include <../fielddeck.scad>;

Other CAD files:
exports/stl/upper_hinge_block_right.stl
exports/stl/lower_right.stl
exports/stl/bottom_cover.stl
scad/fielddeck.scad
exports/stl/cable_cover_long.stl
exports/stl/cable_cover_short.stl
exports/stl/keyboard_plate_left.stl
exports/stl/lower_hinge_block_left.stl
exports/stl/tablet_bracket.stl
scad/parts/assembly_preview.scad
scad/parts/battery_strap.scad
scad/parts/bottom_cover.scad
scad/parts/cable_cover_long.scad
scad/parts/cable_cover_short.scad
scad/parts/closed_preview.scad
scad/parts/fit_coupon.scad
scad/parts/lower_hinge_block_left.scad
scad/parts/lower_hinge_block_right.scad
scad/parts/lower_left.scad
scad/parts/lower_right.scad
scad/parts/tablet_bracket.scad
scad/parts/upper_hinge_block_left.scad
scad/parts/upper_hinge_block_right.scad
scad/parts/upper_lid_back.scad
scad/parts/upper_lid_frame.scad
scad/parts/web_components.scad
scad/parts/web_keycaps.scad
scad/parts/web_shell.scad
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

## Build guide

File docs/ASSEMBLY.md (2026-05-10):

# Ferris FieldDeck 11 Assembly

## Fit Checks First

Print these small parts before the full shell:

1. `tablet_bracket.stl`
2. `lower_hinge_block_left.stl`
3. `keyboard_plate_left.stl`
4. `cable_cover_short.stl`
5. `fit_coupon.stl`

Verify heat-set insert holes, switch cutouts, hinge screw spacing, tablet bracket hook clearance, and tablet pad thickness.

Review `AUDIT.md` before printing large parts. The remaining high-risk dimensions are tablet envelope, hinge screw pattern, and cable service-loop bend behavior.

## Main Assembly

1. Heat-set all M2.5 and M3 inserts.
2. Join `lower_left` and `lower_right` with `lower_center_spine`.
3. Install lower hinge blocks into the rear spine area.
4. Seat the friction hinge leaves into the printed pockets and mount them to the lower hinge blocks.
5. Install the keyboard plates and PCB assemblies into the recessed trays.
6. Route the right keyboard cable through the central cable channel.
7. Install Pro Micro-footprint USB-C RP2040 controller hardware behind the left keyboard half.
8. Mount the power bank or protected battery module in the central bay.
9. Route the USB-C tablet power lead to the rear hinge pass-through.
10. Assemble `upper_lid_frame` and `upper_lid_back`.
11. Install upper hinge blocks and attach the lid to the hinges.
12. Place 0.8-1.0 mm soft pads in the tablet recess and on the bracket hook faces.
13. Install the tablet by seating the lower two brackets first, then sliding the upper two `tablet_bracket` retainers until they overlap the tablet edge by 2.0-2.5 mm.
14. Fit cable covers and verify opening and closing motion.
15. Install `bottom_cover`.
16. Add rubber feet.

## Critical Validation

- Lid holds position at 120-125 degrees.
- Hinge barrels rotate coaxially without rubbing the printed reliefs.
- USB-C loop does not pinch when closing.
- Keycaps clear the lid by at least 1.5 mm.
- Nominal keycap top is at or below 22.6 mm from the lower shell datum.
- Tablet cannot lift out when shaken lightly but can be removed by loosening only the four bracket screws.
- Battery can be removed through the bottom cover.
- No hinge block flex is visible during opening.

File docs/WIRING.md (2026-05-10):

# Ferris FieldDeck 11 Wiring

## Keyboard Architecture

Use a Sweep v2.2-compatible 34-key split keyboard with two Pro Micro-footprint USB-C controllers.

Chosen controller class: SparkFun Pro Micro RP2040 or any pin-compatible USB-C Pro Micro RP2040 board.

Do not use Seeed XIAO RP2040 for this revision. XIAO is smaller, but the available GPIO count is too tight for a direct-pin Sweep-style 17-key half without adding an I/O expander or diode matrix. A Pro Micro-footprint controller keeps the design generic, easy to source, and compatible with existing Sweep firmware work.

## Internal Wiring

| Connection | Cable | Route |
|---|---|---|
| Left keyboard controller USB-C | 100-150 mm right-angle USB-C cable | Left controller to rear keyboard/service USB-C breakout |
| Left-to-right split interconnect | JST-SH 4-pin, 150-180 mm | Central printed cable channel between keyboard wells |
| Tablet power/data lead | Short right-angle USB-C | Lid tablet USB-C to rear hinge service loop |
| PD input | 26-28 AWG silicone wire | Rear USB-C PD board to protected power module |
| USB-A service/accessory | 26-28 AWG silicone wire or short USB pigtail | Rear USB-A board to internal hub/service point |

## JST-SH Split Interconnect Pinout

Use a keyed JST-SH cable instead of an exposed TRRS cable inside the deck.

| JST Pin | Signal | Notes |
|---:|---|---|
| 1 | GND | Common ground between halves |
| 2 | 3V3 or VCC | Match selected controller and firmware wiring |
| 3 | SERIAL | QMK split serial data |
| 4 | RESET | Optional remote reset; may be left NC if not used |

## Controller Placement

The controller envelope in CAD is `34 x 18.5 x 5.0 mm`, which fits a Pro Micro RP2040-class board mounted low behind the left keyboard tray. Keep USB-C connector access pointed toward the rear service port.

## Keyboard PCB Package

Use the vendored Sweep v2.2 Gerber ZIP for first fabrication:

```text
hardware/keyboard/Sweep/Sweep v2.2/sweepv2.2_gerber.zip
```

The cyberdeck-specific placement, wiring, and mechanical carrier design lives here:

```text
hardware/keyboard/fielddeck_sweep_compat/
```

## Build Notes

1. Order the Sweep v2.2 PCB pair from the Gerber ZIP.
2. Populate Choc hotswap or soldered switch footprints according to the Sweep BOM.
3. Socket or solder two Pro Micro RP2040-compatible controllers.
4. Use the left half as USB master.
5. Connect the right half with the keyed JST-SH internal cable.
6. Flash standard Sweep-compatible QMK/ZMK-style firmware adjusted for the selected controller pin names.
7. Install the assembled PCBs into the recessed trays and verify top-of-keycap height is below `22.6 mm` from the lower shell datum.

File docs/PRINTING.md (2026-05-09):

# Ferris FieldDeck 11 Printing Guide

## Materials

Use PETG for the main shell and PETG-CF or nylon for hinge blocks if available.

Recommended baseline:

| Part | Material | Notes |
|---|---|---|
| Lower shell left/right | PETG | Warm grey, matte preferred |
| Lower center spine | PETG or PETG-CF | Structural joiner |
| Upper lid frame | PETG | Use dry filament |
| Upper lid back | PETG | Outer face down |
| Hinge blocks | PETG-CF or nylon | Stronger and stiffer |
| Keyboard plates | PETG-CF or 1.5 mm aluminum | PETG works for prototype |
| Tablet brackets | PETG with TPU/EVA/Poron pads | Print flat; tune hook overlap on fit test |
| Cable covers / strap | PETG | Small utility parts |

## Bambu Lab Slicer Settings

| Setting | Value |
|---|---:|
| Nozzle | 0.4 mm or 0.6 mm |
| Layer height | 0.20 mm |
| Wall loops | 4 |
| Top layers | 5 |
| Bottom layers | 5 |
| Infill | 25% gyroid |
| Sparse infill for hinge blocks | 40% gyroid/cubic |
| Seam | Rear or aligned |
| Supports | Tree/manual supports only where needed |
| PETG nozzle | 245-255 C |
| PETG bed | 75-85 C |
| Brim | Recommended on lower shell halves and lid frame |

## Orientation

| STL | Orientation |
|---|---|
| lower_left.stl | Top face up, rear hinge spine on bed side is acceptable with supports |
| lower_right.stl | Top face up |
| lower_center_spine.stl | Flat face down |
| bottom_cover.stl | Outer face down |
| upper_lid_frame.stl | Screen side up |
| upper_lid_back.stl | Outer face down |
| hinge blocks | Broad screw face down; keep barrel relief horizontal and use local supports if needed |
| keyboard plates | Flat |
| tablet brackets | Flat with hook up; use a small brim if PETG corners lift |

## Post Processing

1. Deburr every screw hole with a 90 degree countersink by hand.
2. Heat-set inserts with a temperature controlled iron.
3. Test M2.5 and M3 screws before final assembly.
4. Add 0.8-1.0 mm TPU, EVA, felt, or Poron pads wherever printed plastic touches the tablet.
5. Dry fit hinge barrels in the printed reliefs and cycle the lid slowly before electronics are installed.

## Export

Run:

```bash
scripts/export_stls.sh
```

This environment may not have OpenSCAD installed. On a workstation with OpenSCAD, the script exports every printable STL to `exports/stl`.

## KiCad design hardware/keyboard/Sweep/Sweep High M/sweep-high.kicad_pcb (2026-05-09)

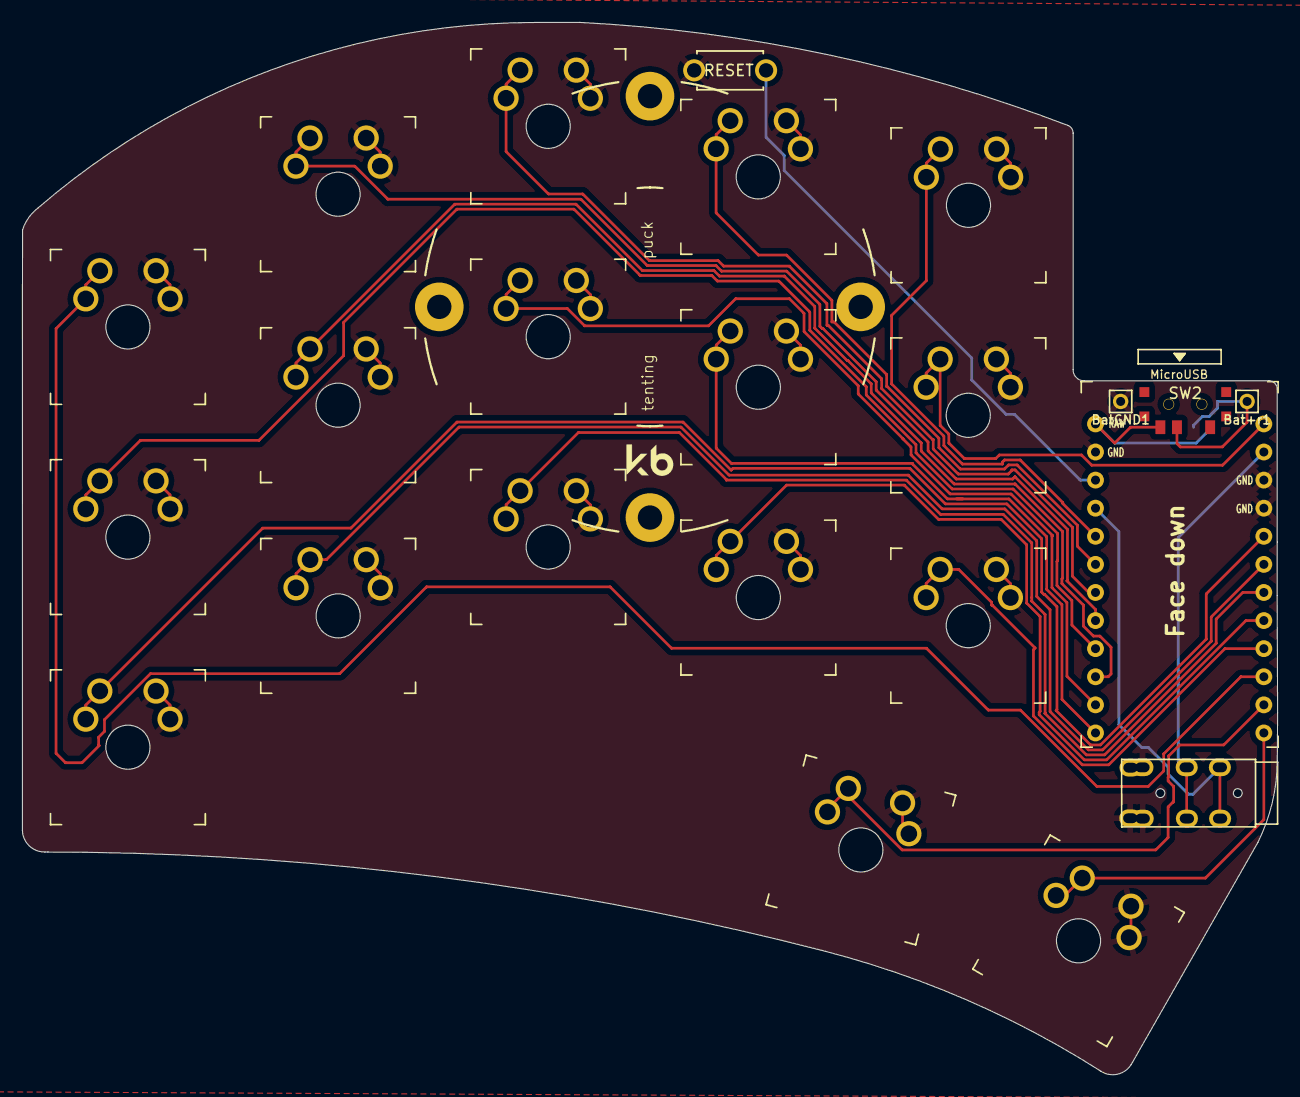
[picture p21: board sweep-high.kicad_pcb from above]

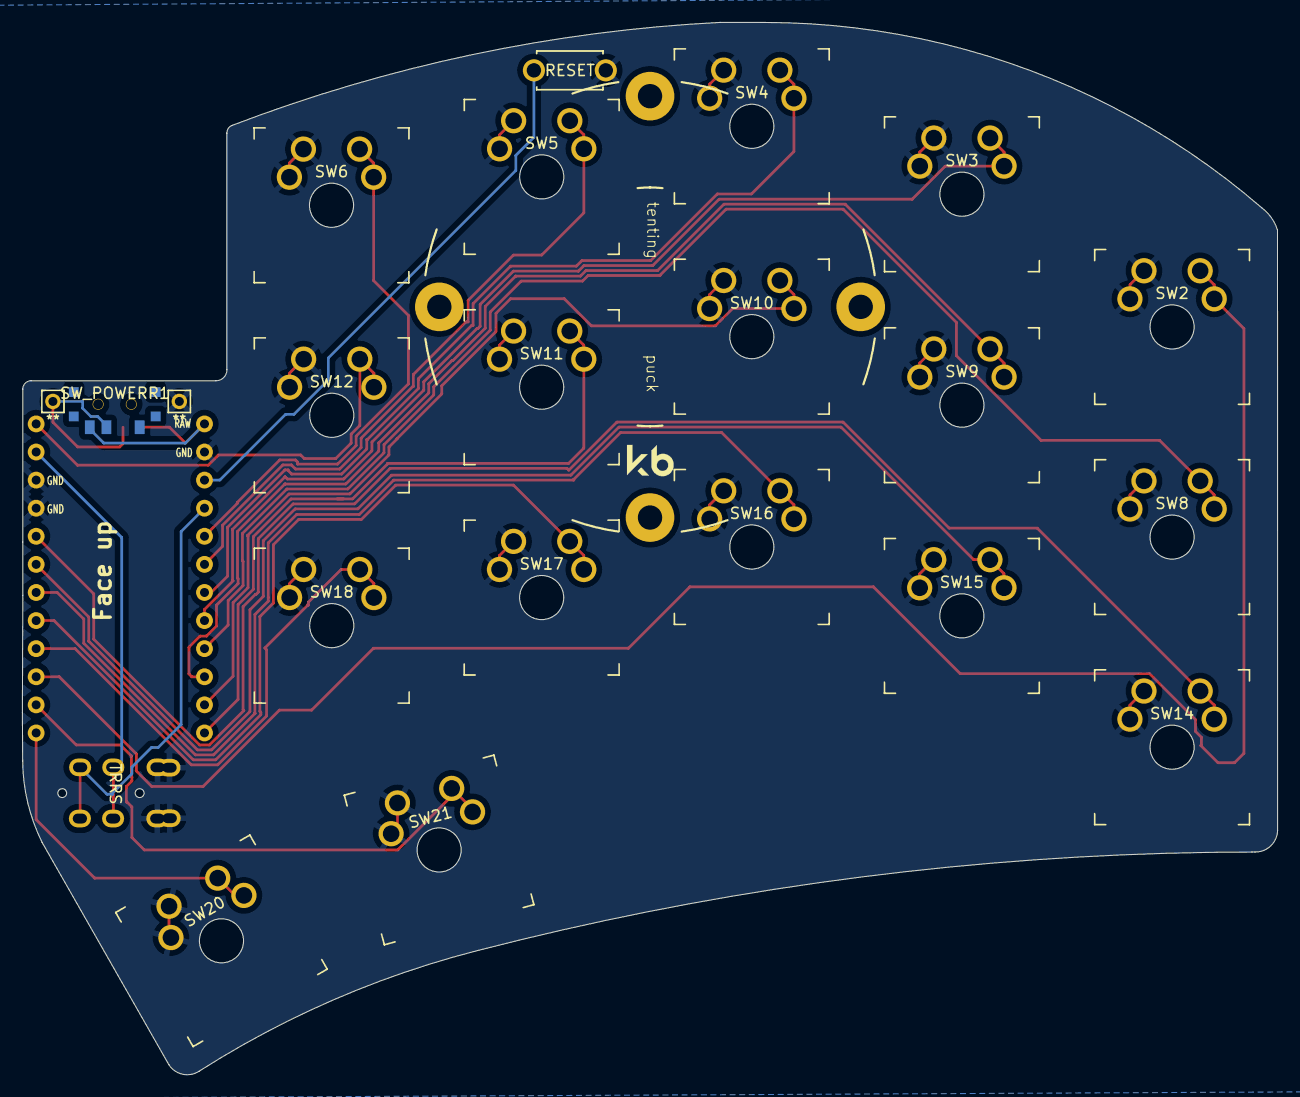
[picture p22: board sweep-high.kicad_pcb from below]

Board: 2 copper layers, 113.5 x 95.2 mm, 24 parts (2 on the bottom side), 23 nets.

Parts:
Bat+r1: MountingHole_Pad; 1pin_conn
BatGND1: MountingHole_Pad; 1pin_conn
J2: AudioJack4dpb; TRRS-PJ-DPB2
RSW1: SW_Push; ResetSW
SW2, SW3, SW4, SW5, SW6, SW8, SW9, SW10, SW11, SW12, SW14, SW15, SW16, SW17, SW18, SW20, SW21: SW_Push; SW_MX_reversible_minimal
SW2#2: SW_SPDT; SPDT_C128955r
SW_POWERR1: SW_SPDT; SPDT_C128955
U1: ProMicro-kbd; ProMicro_v3_min

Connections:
BT+_r: Bat+r1.1, SW2#2.2, SW_POWERR1.2
Switch1: SW2.1, U1.10
Switch2: SW3.1, U1.17
Switch3: SW4.1, U1.18
Switch4: SW5.1, U1.19
Switch5: SW6.1, U1.20
Switch6: SW8.1, U1.16
Switch7: SW9.1, U1.15
Switch8: SW10.1, U1.14
Switch9: SW11.1, U1.13
Switch10: SW12.1, U1.1
Switch11: SW14.1, U1.5
Switch12: SW15.1, U1.6
Switch13: SW16.1, U1.7
Switch14: SW17.1, U1.8
Switch15: SW18.1, U1.9
Switch16: SW21.1, U1.11
Switch17: SW20.1, U1.12
Switch18: J2.R1, U1.2
gnd: BatGND1.1, J2.S, J2.T, RSW1.1, SW2.2, SW3.2, SW4.2, SW5.2, SW6.2, SW8.2, SW9.2, SW10.2, SW11.2, SW12.2, SW14.2, SW15.2, SW16.2, SW17.2, SW18.2, SW20.2, SW21.2, U1.3, U1.4, U1.23
raw: SW2#2.3, SW_POWERR1.3, U1.24
reset: RSW1.2, U1.22
vcc: J2.R2, U1.21

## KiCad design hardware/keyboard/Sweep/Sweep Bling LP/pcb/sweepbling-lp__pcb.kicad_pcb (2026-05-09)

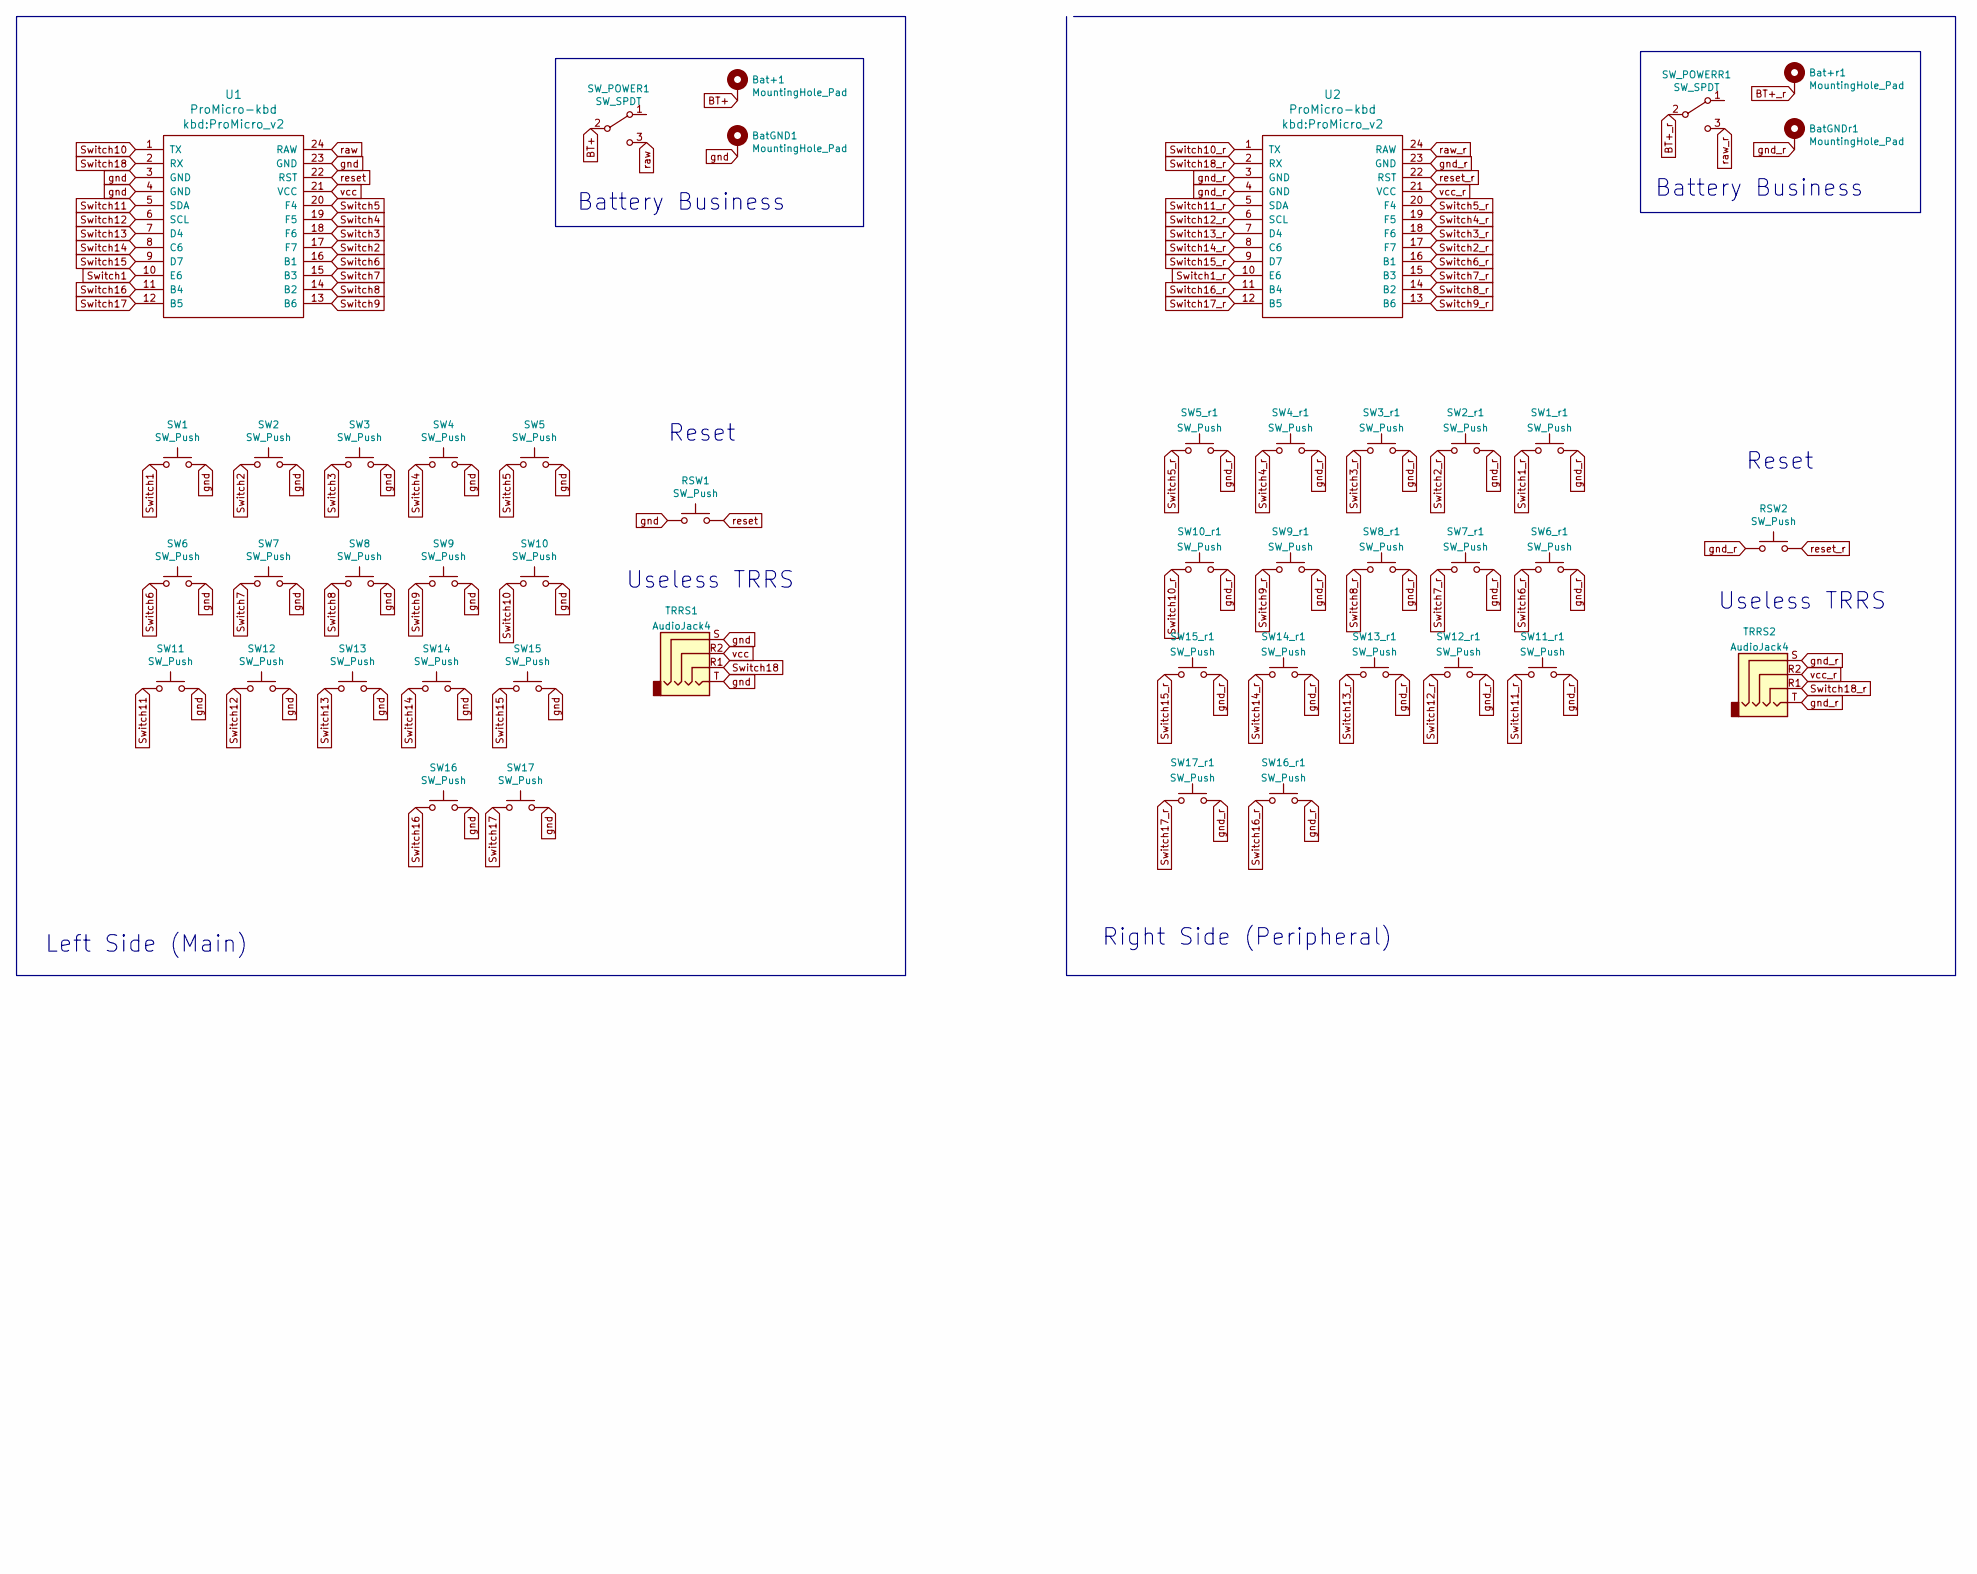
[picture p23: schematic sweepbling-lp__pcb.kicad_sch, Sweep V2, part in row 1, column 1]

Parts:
Bat+1: MountingHole_Pad; 1pin_conn
Bat+r1: MountingHole_Pad; 1pin_conn
BatGND1: MountingHole_Pad; 1pin_conn
BatGNDr1: MountingHole_Pad; 1pin_conn
RSW1, RSW2: SW_Push; ResetSW
SW1, SW1_r1, SW2, SW2_r1, SW3, SW3_r1, SW4, SW4_r1, SW5, SW5_r1, SW6, SW6_r1, SW7, SW7_r1, SW8, SW8_r1, SW9, SW9_r1, SW10, SW10_r1, SW11, SW11_r1, SW12, SW12_r1, SW13, SW13_r1, SW14, SW14_r1, SW15, SW15_r1, SW16, SW16_r1, SW17, SW17_r1: SW_Push; SW_PG1350_rev_DPB
SW_POWER1: SW_SPDT; SPDT_C128955
SW_POWERR1: SW_SPDT; SPDT_C128955
TRRS1, TRRS2: AudioJack4
U1, U2: ProMicro-kbd; ProMicro_v2

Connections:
BT+: Bat+1.1, SW_POWER1.2 (B)
BT+_r: Bat+r1.1, SW_POWERR1.2 (B)
Switch1: SW1.1, U1.10 (E6)
Switch1_r: SW1_r1.1, U2.10 (E6)
Switch2: SW2.1, U1.17 (F7)
Switch2_r: SW2_r1.1, U2.17 (F7)
Switch3: SW3.1, U1.18 (F6)
Switch3_r: SW3_r1.1, U2.18 (F6)
Switch4: SW4.1, U1.19 (F5)
Switch4_r: SW4_r1.1, U2.19 (F5)
Switch5: SW5.1, U1.20 (F4)
Switch5_r: SW5_r1.1, U2.20 (F4)
Switch6: SW6.1, U1.16 (B1)
Switch6_r: SW6_r1.1, U2.16 (B1)
Switch7: SW7.1, U1.15 (B3)
Switch7_r: SW7_r1.1, U2.15 (B3)
Switch8: SW8.1, U1.14 (B2)
Switch8_r: SW8_r1.1, U2.14 (B2)
Switch9: SW9.1, U1.13 (B6)
Switch9_r: SW9_r1.1, U2.13 (B6)
Switch10: SW10.1, U1.1 (TX)
Switch10_r: SW10_r1.1, U2.1 (TX)
Switch11: SW11.1, U1.5 (SDA)
Switch11_r: SW11_r1.1, U2.5 (SDA)
Switch12: SW12.1, U1.6 (SCL)
Switch12_r: SW12_r1.1, U2.6 (SCL)
Switch13: SW13.1, U1.7 (D4)
Switch13_r: SW13_r1.1, U2.7 (D4)
Switch14: SW14.1, U1.8 (C6)
Switch14_r: SW14_r1.1, U2.8 (C6)
Switch15: SW15.1, U1.9 (D7)
Switch15_r: SW15_r1.1, U2.9 (D7)
Switch16: SW16.1, U1.11 (B4)
Switch16_r: SW16_r1.1, U2.11 (B4)
Switch17: SW17.1, U1.12 (B5)
Switch17_r: SW17_r1.1, U2.12 (B5)
Switch18: TRRS1.R1, U1.2 (RX)
Switch18_r: TRRS2.R1, U2.2 (RX)
gnd: BatGND1.1, RSW1.1, SW1.2, SW2.2, SW3.2, SW4.2, SW5.2, SW6.2, SW7.2, SW8.2, SW9.2, SW10.2, SW11.2, SW12.2, SW13.2, SW14.2, SW15.2, SW16.2, SW17.2, TRRS1.S, TRRS1.T, U1.3 (GND), U1.4 (GND), U1.23 (GND)
gnd_r: BatGNDr1.1, RSW2.1, SW1_r1.2, SW2_r1.2, SW3_r1.2, SW4_r1.2, SW5_r1.2, SW6_r1.2, SW7_r1.2, SW8_r1.2, SW9_r1.2, SW10_r1.2, SW11_r1.2, SW12_r1.2, SW13_r1.2, SW14_r1.2, SW15_r1.2, SW16_r1.2, SW17_r1.2, TRRS2.S, TRRS2.T, U2.3 (GND), U2.4 (GND), U2.23 (GND)
raw: SW_POWER1.3 (C), U1.24 (RAW)
raw_r: SW_POWERR1.3 (C), U2.24 (RAW)
reset: RSW1.2, U1.22 (RST)
reset_r: RSW2.2, U2.22 (RST)
vcc: TRRS1.R2, U1.21 (VCC)
vcc_r: TRRS2.R2, U2.21 (VCC)

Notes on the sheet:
Battery Business
Useless TRRS
Reset
Left Side (Main)
Right Side (Peripheral)

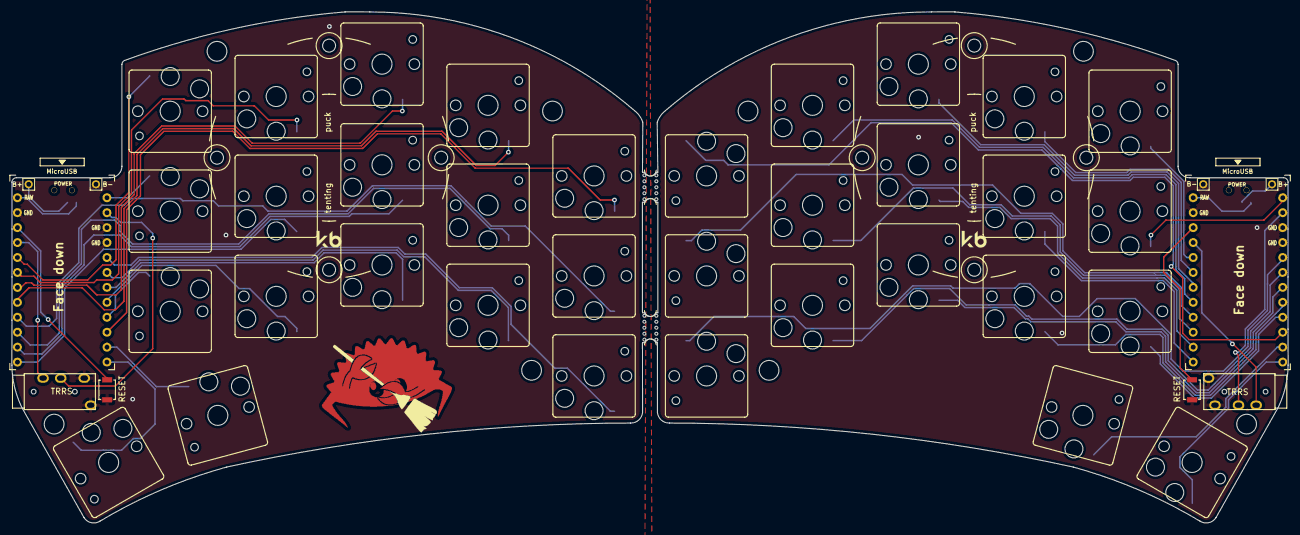
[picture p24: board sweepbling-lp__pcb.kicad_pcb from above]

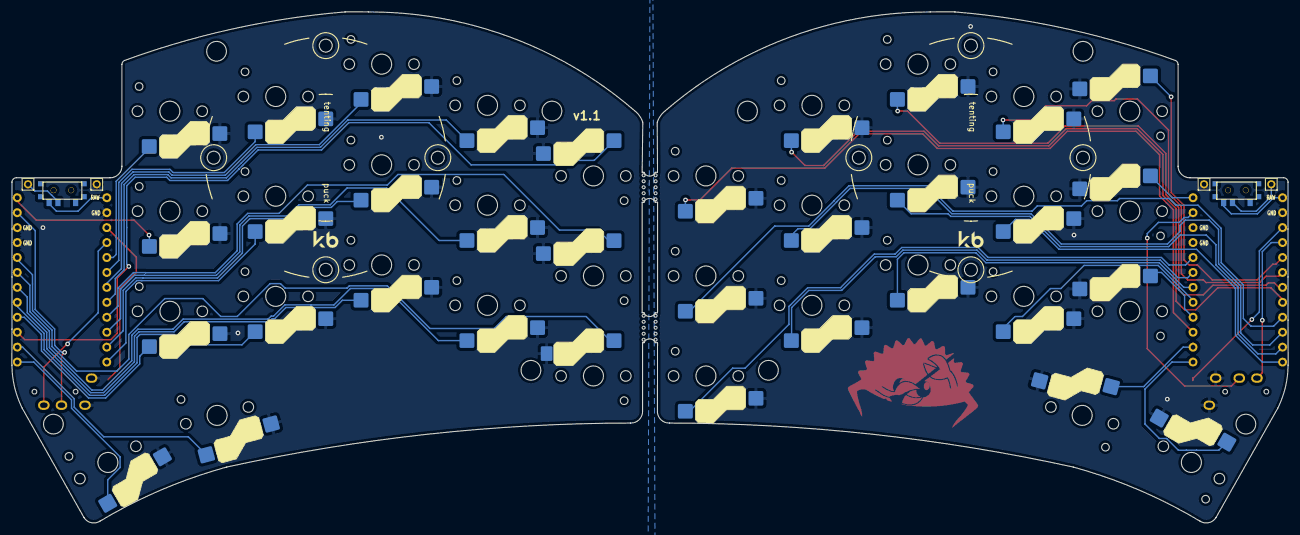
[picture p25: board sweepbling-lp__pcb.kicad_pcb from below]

Board: 2 copper layers, 216.9 x 86.9 mm, 51 parts (2 on the bottom side), 46 nets.

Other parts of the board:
REF_PUCK_R: Tenting Puck; Tenting_Puck2_no_pads
SweepLogo: LOGO; ferris_broom
e: Tenting Puck; Tenting_Puck2_no_pads
mouse-bite-2mm-slot1, mouse-bite-2mm-slot2: VAL**; mouse-bite-5mm-slot-with-space-for-track

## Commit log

2026-05-09 Add interactive cyberdeck design preview
    [assembly_preview.scad, battery_strap.scad, battery_strap.stl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]
2026-05-09 Audit and improve cyberdeck assembly model
    [battery_strap.stl, bottom_cover.stl, cable_cover_long.stl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]
2026-05-09 Lock real parts and slim cyberdeck design
    [battery_strap.stl, bottom_cover.stl, cable_cover_long.stl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]
2026-05-09 Streamline fielddeck mechanical design
    [battery_strap.stl, bottom_cover.stl, cable_cover_long.stl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]
2026-05-10 Audit closure and add keyboard PCB package
    [battery_strap.stl, bottom_cover.stl, cable_cover_long.stl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]
